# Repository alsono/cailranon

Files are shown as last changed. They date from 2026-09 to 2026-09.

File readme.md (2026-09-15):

# introduction
This is an arduino nano powered hand held rail gun that runs on a 24V (12vx2) battery thats somewhat simple to use <br>
this took me more than it should have since i'm generally learning cad (around 9 hours) <br>
24v battery should be charged with crocodile clips as its hooked up via relay <br>
system works on a 5V battery on the side that must be removed before charging <br>
it has a cooldown of 5 seconds after every shot to avoid overheating the coils <br>
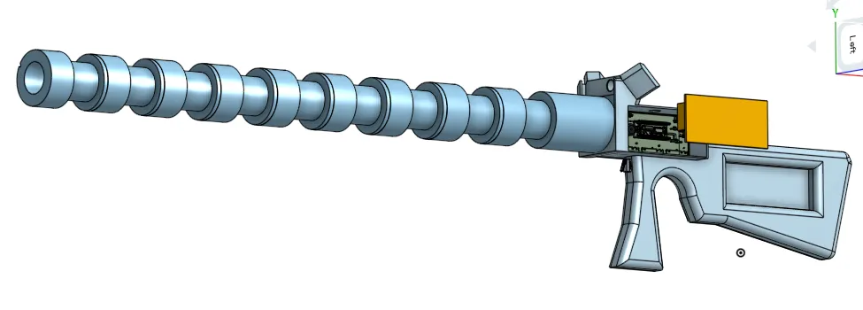
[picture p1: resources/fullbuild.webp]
fih
 <br>
# how to use
load it up like a musket with the metal pellets they use for slingshots, aim at your target and press the trigger, it should make a loud ass beep as it shoots <br>
# what to use this for?
- NOT killing people 
- shooting at soda cans
- killing tomatoes/ref
# how it works
think of it like a 3 step motor, the power cycles between 3 coils in the gun barrel infront of the projectile pulling it forward <br> 
and then cycling to the next one right away <br>
# warning i am not legally accounted with any harm caused from this outside its intended use or during malfunction
## tools you'll need
- soldering iron and solder
- superglue (bear with me)
- hot glue gun (bear with me here)
- acess to a 3d printer (you can use jlc3dp)
## parts you'll need
- check out the bom  (bill of materials)
- order the pcb from jlcpcb.com using the gerber.rar in production files
## how to build
## software
setup steps:
- download arduino ide
- download the file in railgunsoftware
- run it with arduino ide
- attach your arduino nano to your pc
- press the checkmark on the top left and wait for it flash
### printing
first set (or order) these parts to 3d print while you work on the hw:
- the main body with the cover <br>
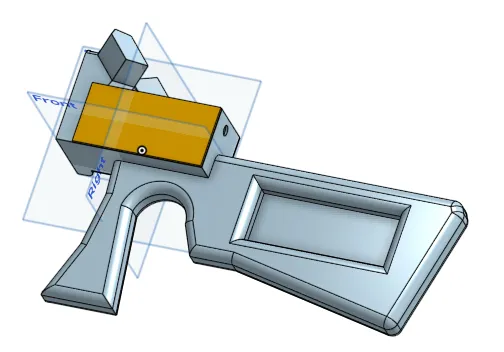
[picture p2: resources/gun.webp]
mainbody
 <br>
- the barrel (if your printer is too small you can split it into 2 and glue it together) <br>
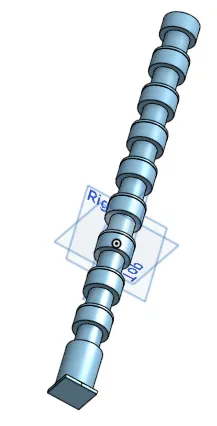
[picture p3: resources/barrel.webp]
barrel
 <br>
note: ideally you should print the barrel laying down so its way more sturdy and doesn't break off <br>
### soldering
solder the components so it looks like this (arduino nano on the bottom) <br>
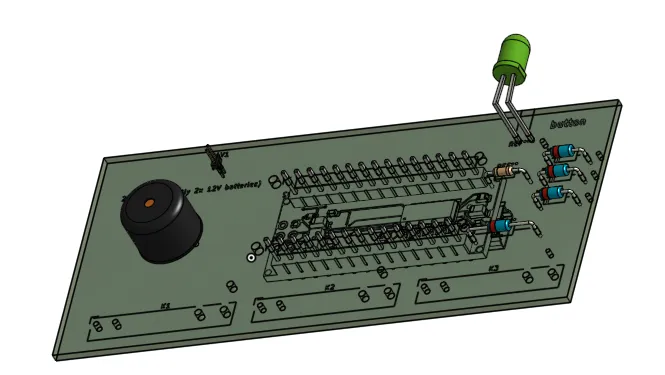
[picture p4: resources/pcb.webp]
pcb3d
 <br>
now solder a wire to each of these <br>
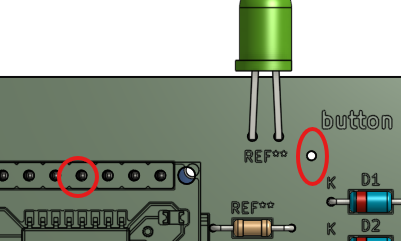
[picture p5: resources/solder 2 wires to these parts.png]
solder 2 wires
 <br>
run said wires through here <br>
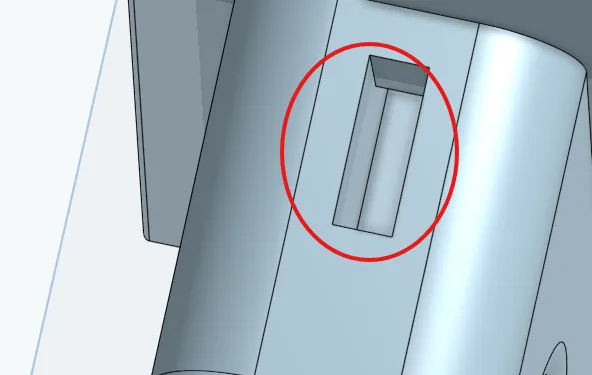
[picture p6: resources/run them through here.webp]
run them switch
 <br>
and then solder them to the switch like so <br>
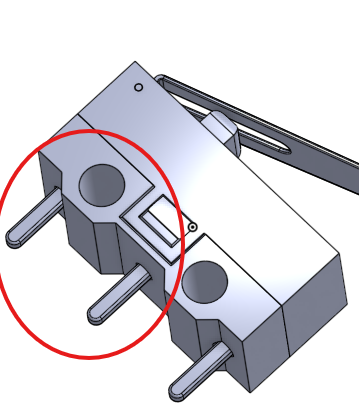
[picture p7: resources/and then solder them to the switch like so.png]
solder them to switch
 <br>
 next solder a 5v battery to the 5v pin on the nano (run the connection through here) <br>
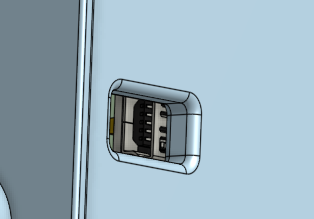
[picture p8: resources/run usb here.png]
porp
  <br>
 and (bear with me) hot glue it to the side <br>
 next grab the 3 relays and wire them to these (relay part pointing down from it) <br>
wire them relay <br>
run the cable through these <br>
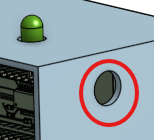
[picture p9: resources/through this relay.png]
holerelay
 <br>
and (bear with me) hot glue them here <br>
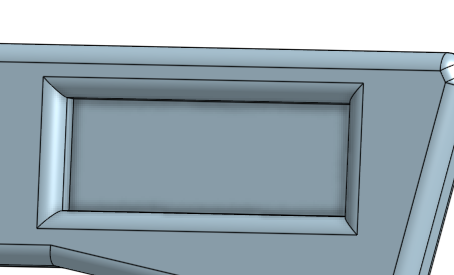
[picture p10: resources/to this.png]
to this
 <br>
grab 2 12V batteries and wire them in series and then wire them here (- is down + is up) and make sure the wire is long enough for you to carry them in a bag <br>
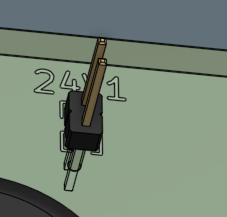
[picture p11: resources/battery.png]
24v
 <br>
last step: <br>
grab 3 of the longest copper wires you can find ideally 1.25mm and run the following equasion <br>

the more wire you have the better just don't over do it <br>
pass the 3 wires from the front through these two holes <br>
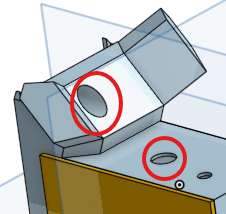
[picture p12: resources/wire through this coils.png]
wire through this coils
 <br>
solder said wires here <br>
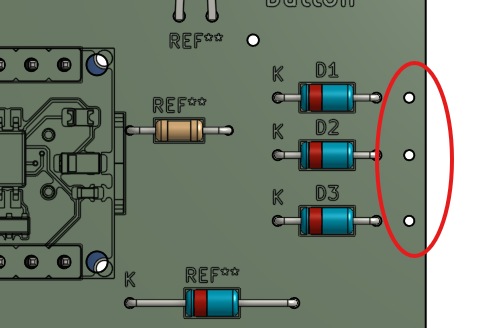
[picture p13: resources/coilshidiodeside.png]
coilshidiodeside
 <br>
run [(your wire length) - 1612mm]/192.71786 on your calculator <br>
the number you get is the amount of turns each coil gets, hope you got a lot of wire!! <br>
do the amount of turns you got on these with the topmost wire you soldered to the diodes around these parts <br>
wraparoundwire1 <br>
drip down superglue onto each coil to both lock it in place and make sure it doesn't short out if the wax layer is burnt off due to usage <br>
now after running it back through the same hole solder it to this part <br>
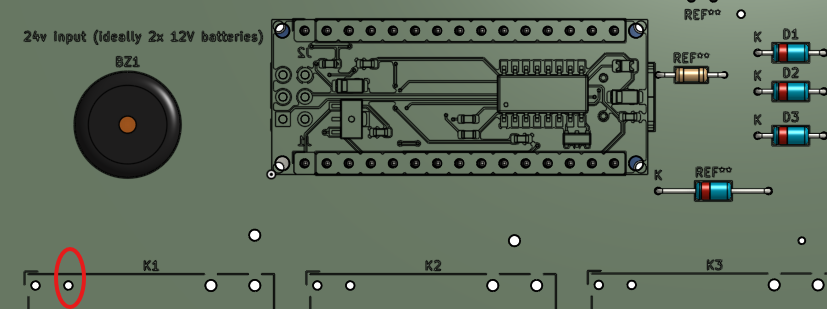
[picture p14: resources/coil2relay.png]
coil1torelay
 <br>
repeat the above 2 more times for the other 2 wires (don't put the coils on top of eachother i meant put wire 2 on every 3rd spot without wire already starting from the 2nd)
# qna
"why don't you hold stuff down with bolts?" gun explodes <br>
"whys there no relay module in the demonstrations?" i could not for the life of me find one and i've spent too much on this project to make one 
## stuff for nerds
the schematic used you can find it in pcb <br>
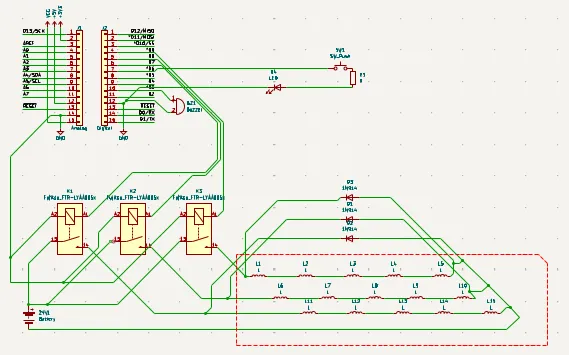
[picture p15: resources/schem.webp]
dsa
<br>
the pcb design wiring <br>
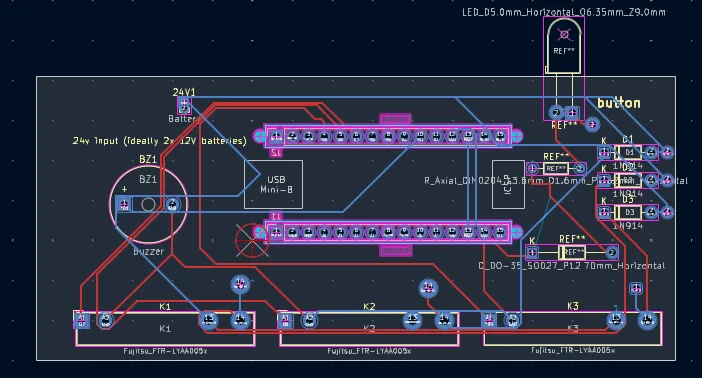
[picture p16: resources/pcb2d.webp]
cbp
<br>
# demo links
- [onshape 3d model](https://cad.onshape.com/documents/b5d65689f200aad3e485e3da/w/5ed7d26aa7ff4d9a5b7cf364/e/11ed56f53a2aa773af70aec3)
- [pcb](https://kicanvas.org/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)

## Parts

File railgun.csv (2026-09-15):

Reference | Value | Datasheet | Footprint | Qty | DNP
12V | Battery |  | Connector_PinHeader_1.00mm:PinHeader_1x02_P1.00mm_Vertical | 2
BZ1 | Passive Buzzer |  | Buzzer_Beeper:Buzzer_12x9.5RM7.6 | 1
D1,D2,D3 | 1N914 | http://www.vishay.com/docs/85622/1n914.pdf | Diode_THT:D_DO-35_SOD27_P7.62mm_Horizontal | 3
D4 | LED |  |  | 1
J1 | Analog |  | Connector_PinHeader_2.54mm:PinHeader_1x15_P2.54mm_Vertical | 1
J2 | Digital |  | Connector_PinHeader_2.54mm:PinHeader_1x15_P2.54mm_Vertical | 1
K1,K2,K3 | Fujitsu_FTR-LYAA005x | https://www.fujitsu.com/sg/imagesgig5/ftr-ly.pdf | Relay_THT:Relay_SPST-NO_Fujitsu_FTR-LYAA005x_FormA_Vertical | 3
L1,L2,L3,L4,L5,L6,L7,L8,L9,L10,L11,L12,L13,L14,L15 | L |  |  | 15
R1 | R |  |  | 1
SW1 |  |  | Button_Switch_SMD:SW_SP3T_PCM13 | 1
mh |  |  | longest wire you can find | 3
arduino_nano |  | any |  | 1

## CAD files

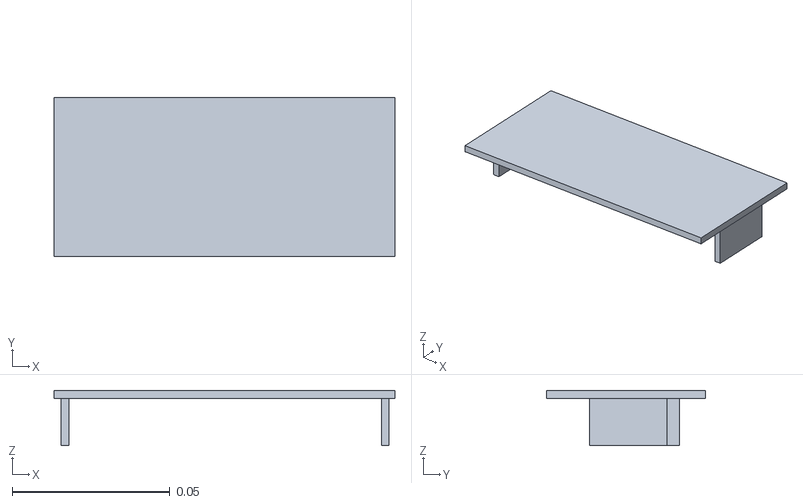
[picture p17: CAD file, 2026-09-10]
production files/gun main body cover.stl
0.108 x 0.0504 x 0.0175

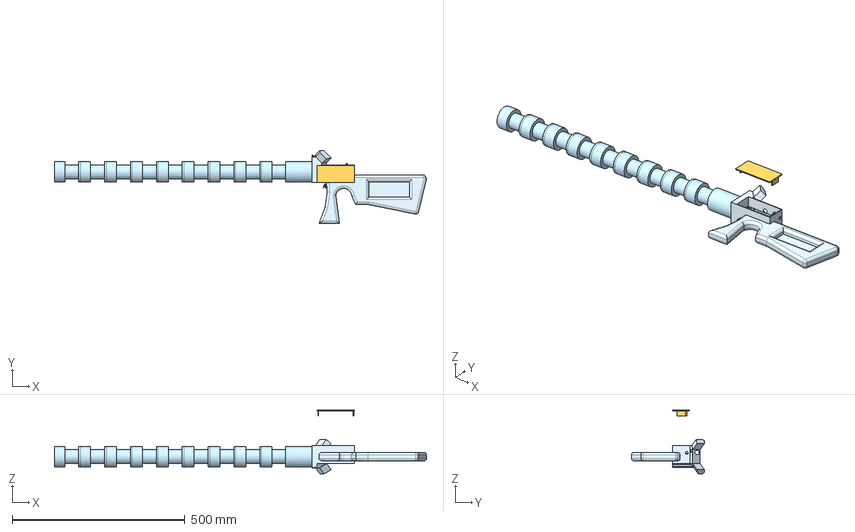
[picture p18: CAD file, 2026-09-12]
full render/full build render.step
1078.1 x 211.3 x 184.7 mm
topTracks_6dc x 167
botTracks_6dc x 131
railgun_silkscreen x 109
railgun_PCB
D_DO-35_SOD27_P7.62mm_Horizontal x 6
topSilks_7595 x 137
railgun_soldermask x 2
Button__Fillet1
PinHeader_1x02_P100mm_Vertical
J1_USB_Mini-B_Lumberg_2486_01_Horizontal_5F4AD4E6 x 8
Top__Cut-Extrude2
Buzzer_12x95RM76
Bottom__Cut-Extrude1
Pins__Fillet2 x 3
Lever__Fillet2
U3_SOT_89_3_5F4BFB48
R_Axial_DIN0204_L36mm_D16mm_P762mm_Horizontal
D_DO-35_SOD27_P12.70mm_Horizontal
LED_D5.0mm_Horizontal_O6.35mm_Z9.0mm

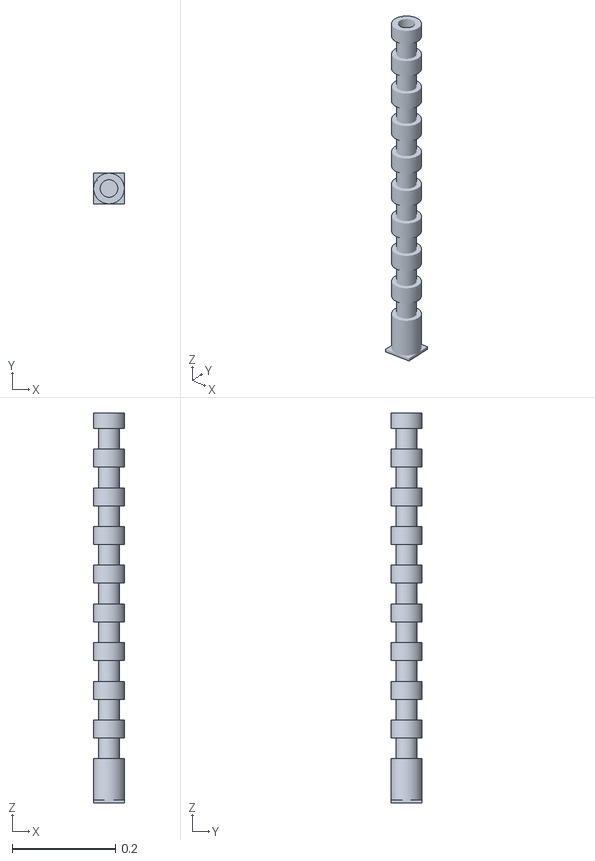
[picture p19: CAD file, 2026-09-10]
production files/full barrel.stl
0.0596 x 0.0595 x 0.756

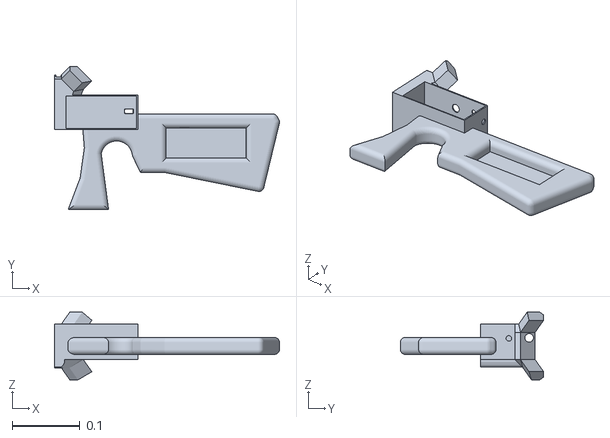
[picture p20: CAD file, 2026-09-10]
production files/gun main body.stl
0.332 x 0.211 x 0.0999

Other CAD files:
full render/railgun.FCStd

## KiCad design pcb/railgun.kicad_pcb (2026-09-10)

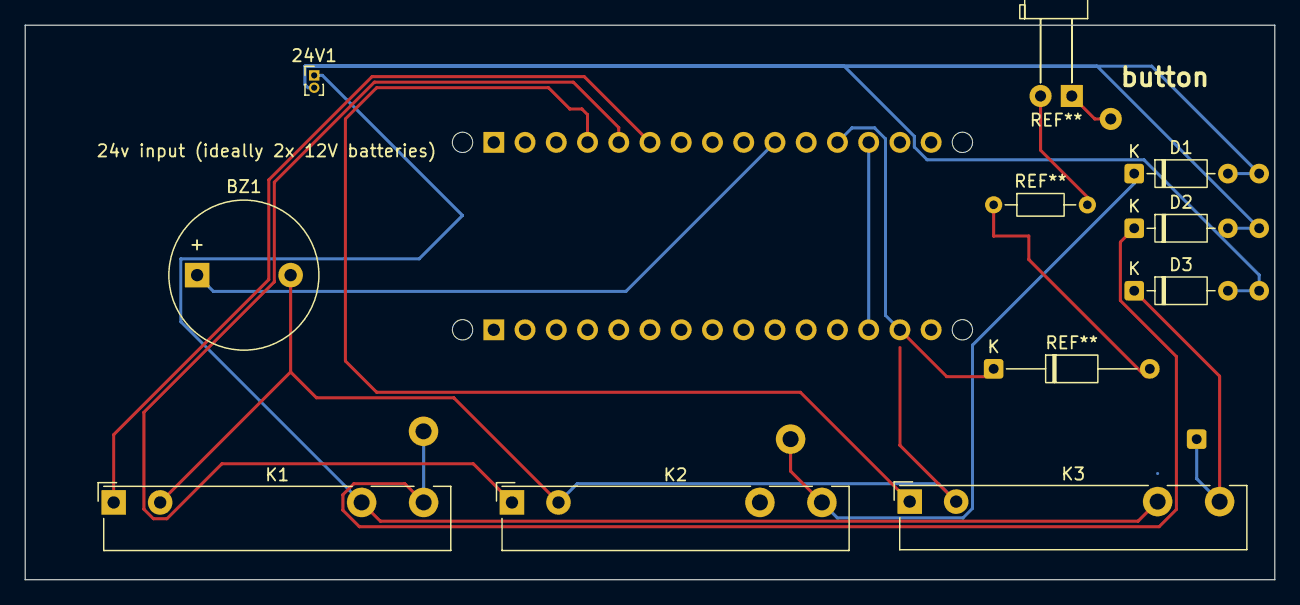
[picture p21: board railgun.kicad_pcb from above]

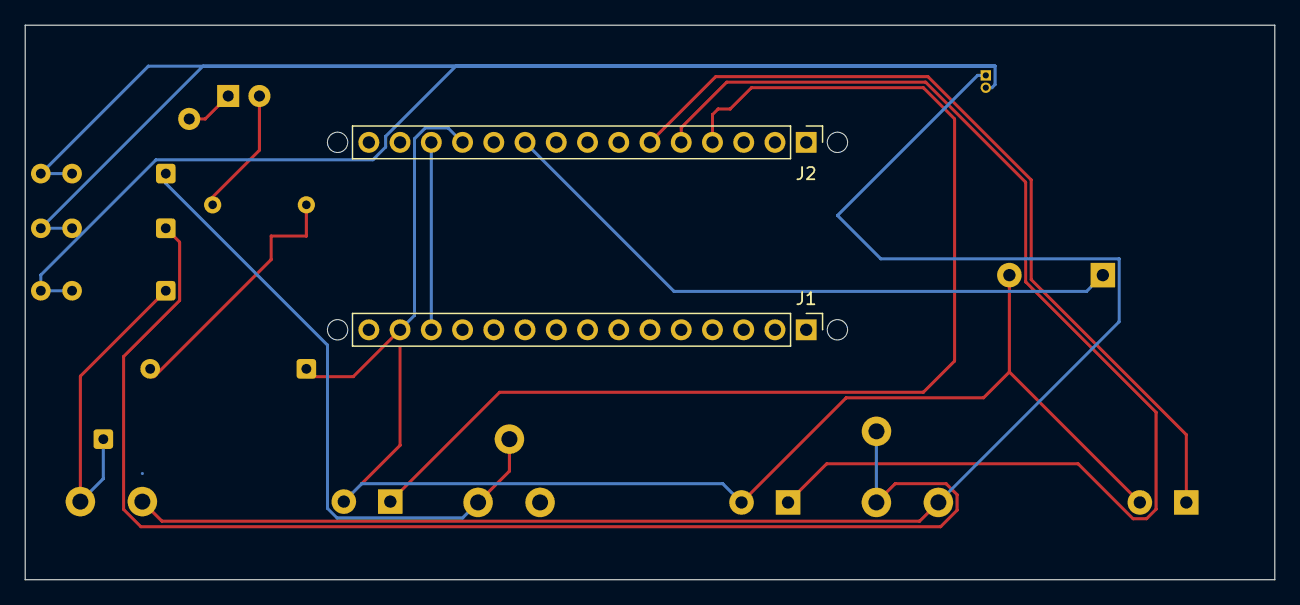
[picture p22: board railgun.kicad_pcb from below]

Board: 2 copper layers, 101.6 x 45.1 mm, 14 parts (2 on the bottom side), 11 nets.

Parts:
24V1: Battery; PinHeader_1x02_P1.00mm_Vertical
BZ1: Buzzer; Buzzer_12x9.5RM7.6
D1, D2, D3: 1N914; D_DO-35_SOD27_P7.62mm_Horizontal
J1: Analog; PinHeader_1x15_P2.54mm_Vertical
J2: Digital; PinHeader_1x15_P2.54mm_Vertical
K1, K2, K3: Fujitsu_FTR-LYAA005x; Relay_SPST-NO_Fujitsu_FTR-LYAA005x_FormA_Vertical
MH1, MH2, MH3, MH4: MountingHole_65mil

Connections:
/*D3: BZ1.1 (+), J2.10
/*D9: J2.4, K3.A1
/D7: J2.6, K1.A1
/D8: J2.5, K2.A1
/~RESET: J1.13, J2.13
GND: BZ1.2 (-), J1.14, J2.12, K1.A2, K2.A2, K3.A2
unnamed: 24V1.1 (+), K1.13, K3.13
unnamed: 24V1.2 (-), D1.2 (A), D2.2 (A), D3.2 (A)
unnamed: D1.1 (K), K2.14
unnamed: D2.1 (K), K1.14
unnamed: D3.1 (K), K3.14

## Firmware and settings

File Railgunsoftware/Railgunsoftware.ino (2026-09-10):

void setup() {
  int shooty = 0
  // the uhh button for shooting:
  pinMode(7, INPUT);
  // the thing that beeps when you ow:
  pinMode(10, OUTPUT);
  // the coils that shoot stuff:
  pinmode(4, OUTPUT);
  pinmode(5, OUTPUT);
  pinmode(6, OUTPUT);
}

void loop() {
shooty = digitalRead(7);
if val > 0 {
  tone(10, 900)
  digitalWrite(4, HIGH);
  delay(20);
  digitalWrite(4, LOW);
  digitalWrite(5, HIGH);
  delay(20);
  digitalWrite(5, LOW);
  digitalWrite(6, HIGH);
  delay(20);
  digitalWrite(6, LOW);
  digitalWrite(7, HIGH);
  digitalWrite(4, HIGH);
  delay(20);
  digitalWrite(4, LOW);
  digitalWrite(5, HIGH);
  delay(20);
  digitalWrite(5, LOW);
  digitalWrite(6, HIGH);
  delay(20);
  digitalWrite(6, LOW);
  digitalWrite(7, HIGH);
  digitalWrite(4, HIGH);
  delay(20);
  digitalWrite(4, LOW);
  digitalWrite(5, HIGH);
  delay(20);
  digitalWrite(5, LOW);
  digitalWrite(6, HIGH);
  delay(20);
  digitalWrite(6, LOW);
  digitalWrite(7, HIGH);
  noTone(10)
  delay(5000)
}


}
